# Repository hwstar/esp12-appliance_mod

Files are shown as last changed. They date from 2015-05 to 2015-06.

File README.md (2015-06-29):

**esp12-appliance_mod**
==========
This is a hardware implementation for my ESP8266-MQTT-io-node project.

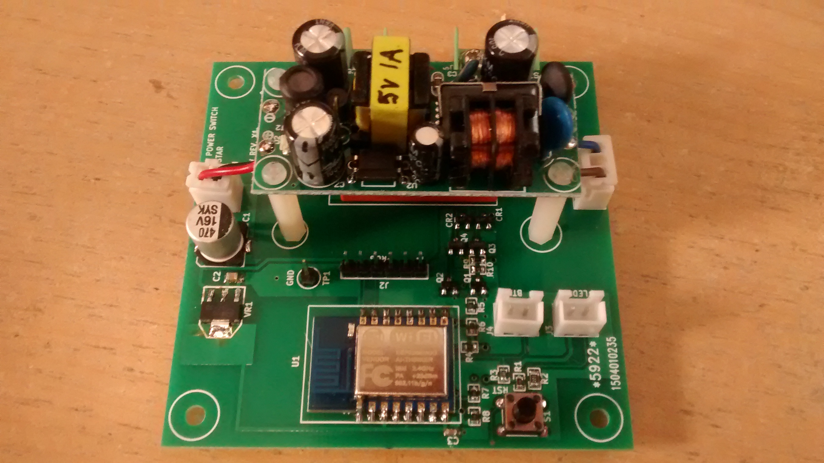
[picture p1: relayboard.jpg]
ProjectPicture


**Features:**

Provides one bistable latching relay channel. Connectors are provided for a link LED and a local button to latch and unlatch the relay.
A dual voltage isolated power supply mounts over the top of the latching relay. The relay is capable of switching  a 16 Amp resistive load at 250VAC, or
a 20 Amp resistive load at 125VAC. See relay data sheet for further details. There are screw terminals for attaching the AC wiring  at the rear of the board (behind the power supply).

**EDA Software**

This board was designed using KICAD. 

**Board Size**

10cm x 10cm

**Board Blank Availability**

Board Blanks are available on Tindie:

https://www.tindie.com/products/hwstarsr/board-blank-for-esp12-appliancemod

**Firmware**

The firmware for this project can be found here:

https://github.com/hwstar/ESP8266-MQTT-io-node

**LICENSE**

Creative Commons Attribution Share-Alike license. (CC-BY-SA)

**Disclaimer**

Build and use at your own risk. This board design uses lethal mains voltages. I will not be responsible for any damages including but not limited to: errors or omissions, loss of life, or property damage. You have been warned.

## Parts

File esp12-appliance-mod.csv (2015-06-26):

Item | Part Number | Qty | Reference(s) | Title/Description | Value on Schematic | Manufacturer | Manufacturer Part Number
1 | 800126-477 | 1 | C1 | CAP,ELECT,8MM,GP,470u,16V | 470 | Open Market | N/A
2 | 800003-106 | 1 | C2 | CAP,0805,10u,25V,X5R | 10U | Open Market | N/A
3 | 800000-104 | 2 | C3,C4 | CAP,0603,0.1u,25V,X7R | 0.1U | Open Market | N/A
4 | 800127-101 | 2 | CR1,CR2 | DIODE,SCHOTTKY,SGL,SOT-23 | BAT54_ | Diodes Inc. | BAT54-7-F
5 | 800125-500 | 1 | F1 | FUSE,0.5A,SLO-BLOW,8.5 X 8 MM,RADIAL | FUSE | Littelfuse | 3720500
6 | 800114-102 | 3 | J1,J3,J4 | CONN,HDR,SHROUDED,2 CKT,5MM,XH SERIES | CONN2 | JST | B2B-XH-A
7 | 800116-106 | 1 | J2 | CONN,HDR,6CKT,0.1PITCH,BERGSTRIP | CONN6 | Open Market | N/A
8 | 800124-101 | 1 | J5 | CONN,HDR,SHROUDED,2PIN IN 3PIN HSG, XH | CONN2-3HSG | Open Market | N/A
9 | 800129-102 | 2 | J6,J7 | CONN,TERM BLK,2 POS,7.62MM PITCH | CONN2-TB762 | Open Market | KF7.62-2P
10 | 800128-101 | 1 | K1 | RELAY,5V,LATCHING,SPDT,DUAL COIL,16A,250V | RELAY_TE_RE314F05 | Tyco Electronics | 8-1393239-5
11 | 800110-101 | 2 | Q1,Q2 | XSTR,GP,NPN,40V,SOT23 | MMBT4401 | Fairchild Semiconductor | MMBT4401
12 | 800123-101 | 2 | Q3,Q4 | XSTR,MOSFET,N-CH,4.0A,30V,SOT-23 | DMN3112 | Diodes Inc. | DMN3112S-7
12 |  |  |  |  |  | Vishay | SI2306BDS-T1-E3
13 | 800010-103 | 4 | R1,R4,R5,R7 | RES,0603,10K OHM,5% | 10K | Open Market | N/A
14 | 800010-473 | 4 | R6,R8-R10 | RES,0603,47K OHM,5% | 47K | Open Market | N/A
15 | 800011-221 | 1 | R2 | RES,0805,220 OHM,5% | 220 | Open Market | N/A
16 | 800010-102 | 1 | R3 | RES,0603,1K OHM,5% | 1K | Open Market | N/A
17 | 800107-101 | 1 | S1 | SWITCH, TACT, 6MM | SW_TACT | Open Market | N/A
18 | 800106-101 | 1 | U1 | MODULE,WIFI,ESP12 | ESP8266-ESP-12 | Open Market | N/A
19 | 800121-101 | 1 | VR1 | IC,VREG,3.3V,1A,SOT-223 | NCP1117ST33 | On Semiconductor | NCP1117ST33T3G
 | Power Supply Sub-assembly
1 | XXXXXX-XXX | 1 | PSU | PSU, 5V, 1A, UNIV INPUT, ISOLATED | Open Market | Ebay 351211320656 | see picture, hole pattern must match main board.
2 | XXXXXX-XXX | 1 |  | CONN, PLUG 3 POS | Open Market | Ebay | JST XH series knockoff*
3 | XXXXXX-XXX | 1 |  | CONN, PLUG 2 POS | Open Market | Ebay | JST XH series knockoff*
4 | XXXXXX-XXX | 4 |  | CONTACT, JST XH SERIES | Open Market | Ebay | JST XH series knockoff*
5 | XXXXXX-XXX | 0.001 |  | WIRE, 24 AWG, UL 1007 | Open Market | Ebay
6 | XXXXXX-XXX | 4 |  | Nylon Standoff M2 20mm | Open Market | Ebay
7 | XXXXXX-XXX | 4 |  | Nylon Nut M2 | Open Market | Ebay
8 | XXXXXX-XXX | 4 |  | Nylon Screw M2 6mm | Open Market | Ebay
 | * |  | A small kit of JST XH compatible
 |  |  | connectors is available on Ebay
 |  |  | under item 141292096528
 |  |  | This will have all of the headers
 |  |  | pins and housings you need
 |  |  | to build the project.

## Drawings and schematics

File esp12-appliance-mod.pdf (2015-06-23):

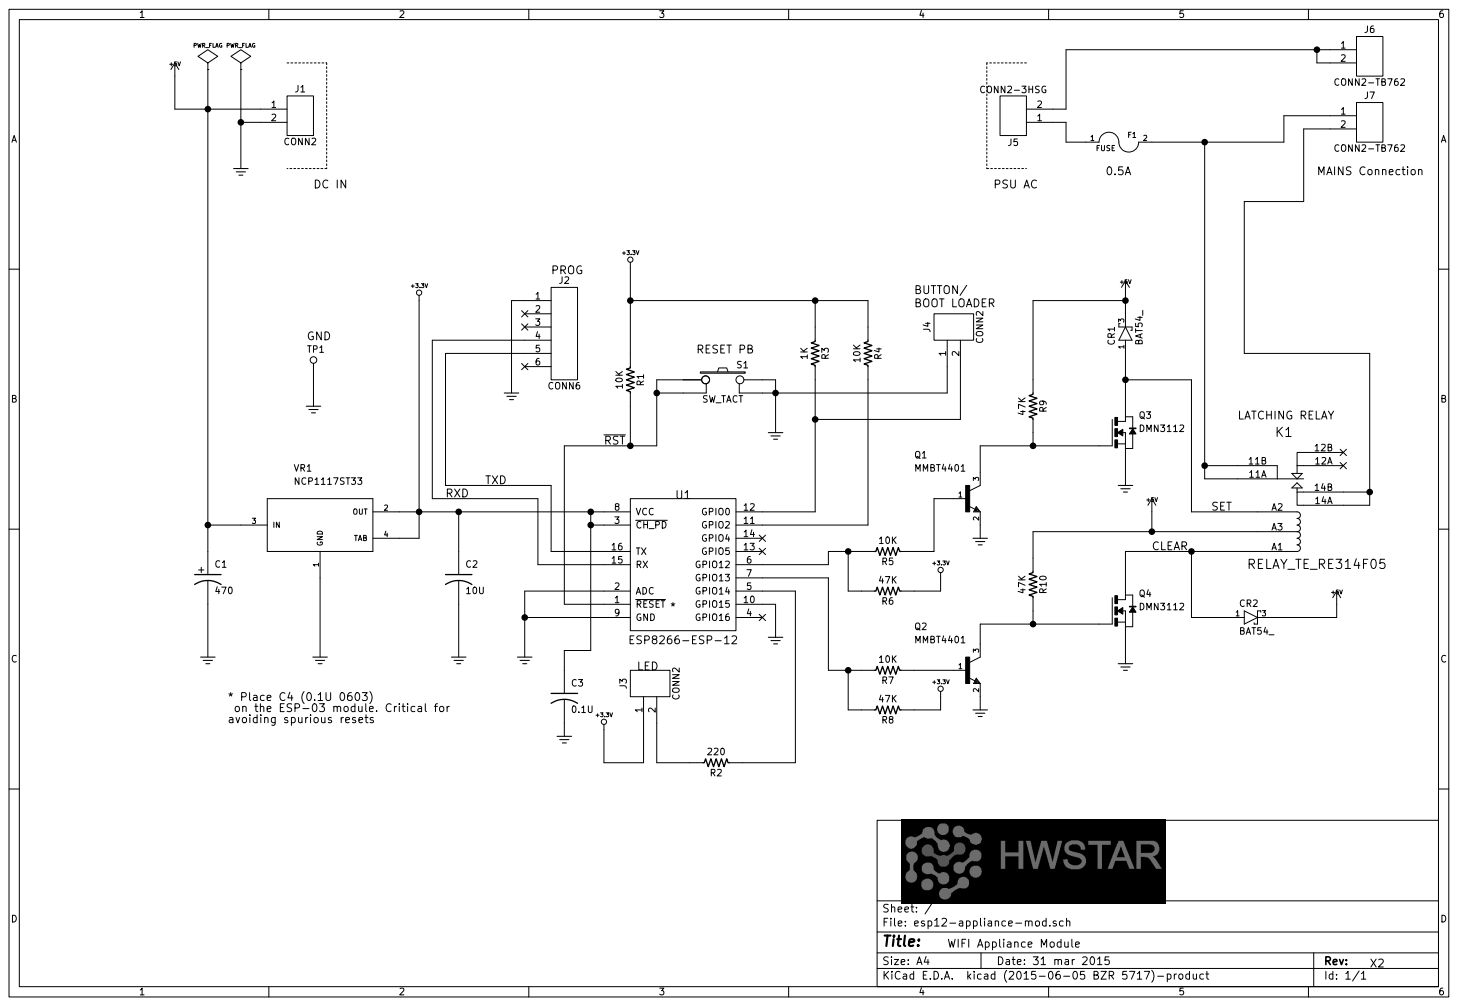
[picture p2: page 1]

File: esp12-appliance-mod.sch Sheet: / GND

* Place C4 (0.1U 0603)
on the ESP-03 module. Critical for

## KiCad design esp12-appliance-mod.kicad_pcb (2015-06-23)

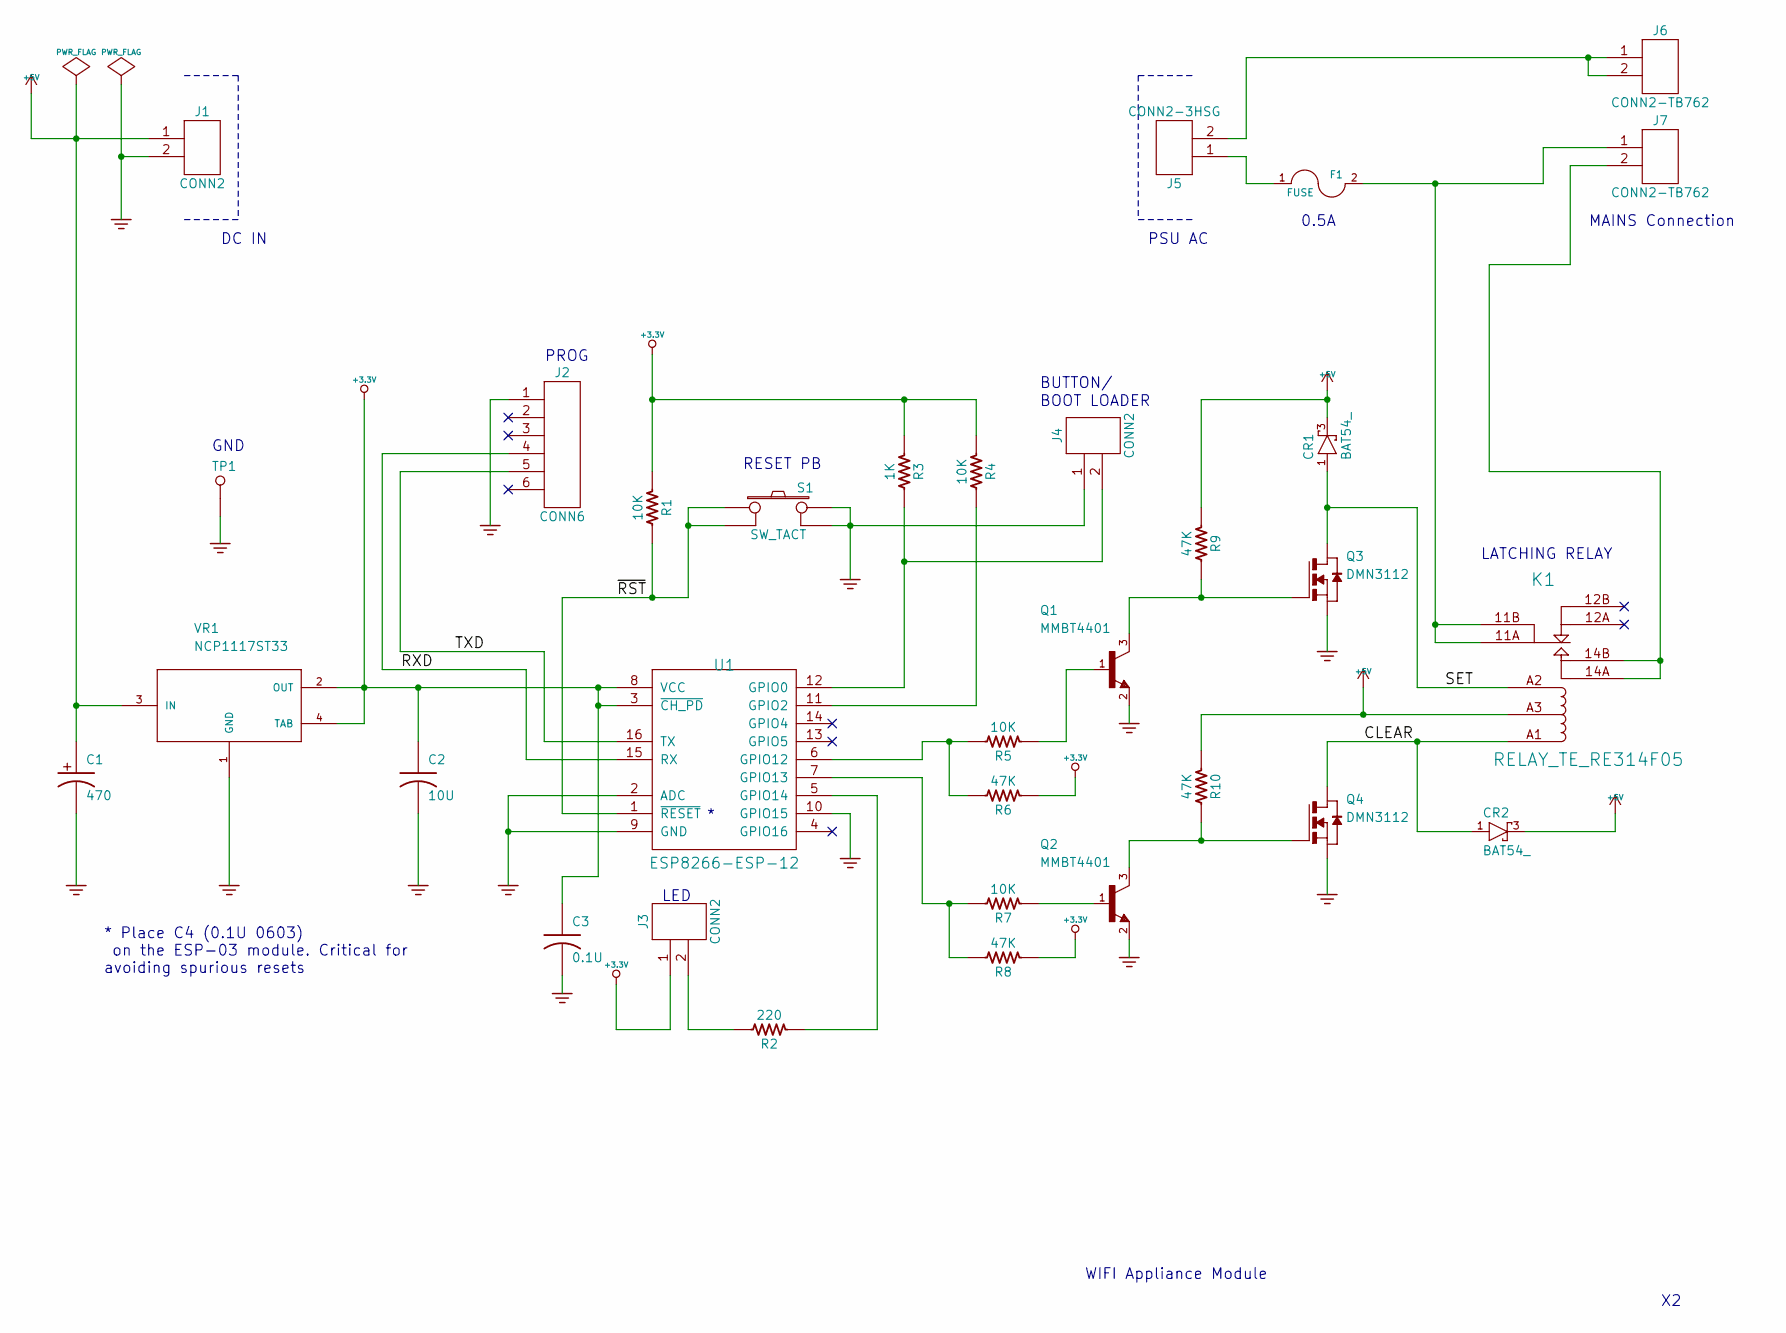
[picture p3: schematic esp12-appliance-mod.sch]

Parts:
C1: 470; PartNumber 800126-477
C2: 10U; CC0805; PartNumber 800003-106
C3: 0.1U; PartNumber 800000-104
CR1, CR2: BAT54_; SOT23; PartNumber 800127-101
F1: FUSE; PartNumber 800125-500
J1, J3, J4: CONN2; PartNumber 800114-102
J2: CONN6; PartNumber 800116-106
J5: CONN2-3HSG; PartNumber 800124-101
J6, J7: CONN2-TB762; PartNumber 800129-102
K1: RELAY_TE_RE314F05; PartNumber 800128-101
Q1, Q2: MMBT4401; SOT23; PartNumber 800110-101
Q3, Q4: DMN3112; SOT23; PartNumber 800123-101
R1, R4, R5, R7: 10K; RC0603; PartNumber 800010-103
R2: 220; RC0805; PartNumber 800011-221
R3: 1K; RC0603; PartNumber 800010-102
R6, R8, R9: 47K; RC0603; PartNumber 800010-473
R10: 47K; RC0603
S1: SW_TACT; PartNumber 800107-101
TP1: TESTPINTPSQ025; TESTPINSQ025
U1: ESP8266-ESP-12; PartNumber 800106-101
VR1: NCP1117ST33; SOT223; PartNumber 800121-101

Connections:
+3.3V: C2.1, C3.1, J3.1, R1.1, R3.1, R4.1, R6.1, R8.1, U1.3 (~CH_PD), U1.8 (VCC), VR1.2 (OUT), VR1.4 (TAB)
+5V: C1.1, CR1.3 (C), CR2.3 (C), J1.1, K1.A3, R9.1, R10.1, VR1.3 (IN)
/CLEAR: CR2.1 (A), K1.A1 (RESET), Q4.3 (D)
/RXD: J2.4, U1.15 (RX)
/SET: CR1.1 (A), K1.A2 (SET), Q3.3 (D)
/TXD: J2.5, U1.16 (TX)
/~RST: R1.2, S1.1, S1.2, U1.1 (~RESET)
GND: C1.2, C2.2, C3.2, J1.2, J2.1, J4.1, Q1.2 (E), Q2.2 (E), Q3.2 (S), Q4.2 (S), S1.3, S1.4, TP1.1, U1.2 (ADC), U1.9 (GND), U1.10 (GPIO15), VR1.1 (GND)
unnamed: F1.1, J5.1
unnamed: F1.2, J7.1, K1.11A (C), K1.11B (C)
unnamed: J3.2, R2.2
unnamed: J4.2, R3.2, U1.12 (GPIO0)
unnamed: J5.2, J6.1, J6.2
unnamed: J7.2, K1.14A (NO), K1.14B (NO)
unnamed: Q1.1 (B), R5.1
unnamed: Q1.3 (C), Q3.1 (G), R9.2
unnamed: Q2.1 (B), R7.1
unnamed: Q2.3 (C), Q4.1 (G), R10.2
unnamed: R2.1, U1.5 (GPIO14)
unnamed: R4.2, U1.11 (GPIO2)
unnamed: R5.2, R6.2, U1.6 (GPIO12)
unnamed: R7.2, R8.2, U1.7 (GPIO13)

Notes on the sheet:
RESET PB
BOOT LOADER
WIFI Appliance Module
LED
DC IN
0.5A
* Place C4 (0.1U 0603) on the ESP-03 module. Critical for avoiding spurious resets
MAINS Connection
PSU AC
BUTTON/
PROG
LATCHING RELAY
GND

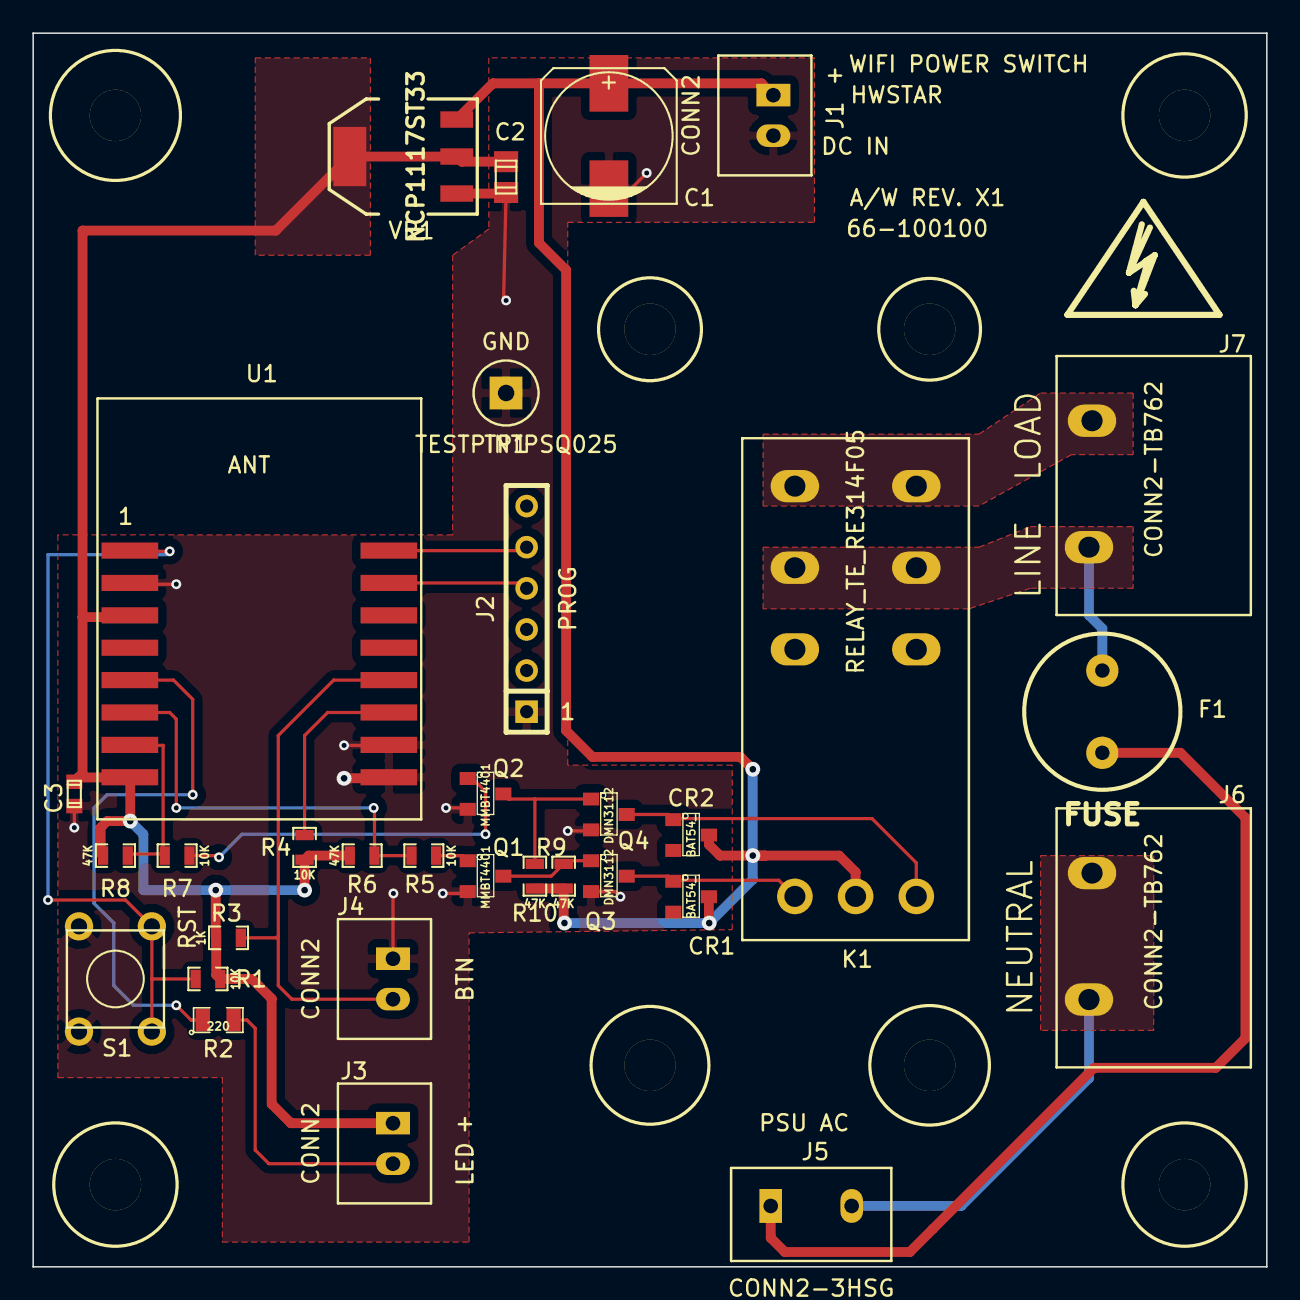
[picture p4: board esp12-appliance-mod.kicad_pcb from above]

Board: 2 copper layers, 76.2 x 76.2 mm, 41 parts (0 on the bottom side), 22 nets.

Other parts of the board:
MTGHOLE125, MTGHOLE125#2, MTGHOLE125#3, MTGHOLE125#4, MTGHOLE125#5, MTGHOLE125#6, MTGHOLE125#7, MTGHOLE125#8: VAL**; MTGHOLE125
Sym: Symbol_HighVoltage_Type2_SilkTop_VerySmall

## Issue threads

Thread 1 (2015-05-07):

PSU item

poundy, 2015-05-07:
It would make sense to list an item # for an eBay PSU unit that you had used, for reference.  In either Readme or BOM would work.

hwstar, 2015-05-07:
I bought 5 of them under ebay item #351211320656. This seller has since re-listed a similar power supply under a new item number which Ebay will direct you to. The board is laid out with a hole spacing of 1.79 by 0.675. The power supplies I received are 2.037 long by 0.930 wide and have 4 mounting holes.

Closed 2015-05-07.

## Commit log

2015-05-06 Initial checkin
    [esp12-appliance-mod.kicad_pcb, esp12-appliance-mod.sch]
2015-05-07 Update BOM with Ebay items numbers for critical parts
    [BOM.xlsx]
2015-06-03 Board size is 10cm X 10cm
2015-06-23 Add part numbers to schematic. Regenerate BOM using BOMTools
    [BOM.xlsx, esp12-appliance-mod.csv, esp12-appliance-mod.kicad_pcb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]
2015-06-23 Update schematic
2015-06-26 Fix BOM error. Add capacitor C4.
    [esp12-appliance-mod.csv]
2015-06-26 Add capacitor C4 which goes between the ESP12 reset pin and the ESP12 case.
    [esp12-appliance-mod.csv]
